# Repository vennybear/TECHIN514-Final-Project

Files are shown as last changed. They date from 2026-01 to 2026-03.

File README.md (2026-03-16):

# Door Detective: Privacy-First Ambient Entry System

> **"A smart doorbell that hears the rhythm, not the person."**

**Door Detective** is a "Calm Technology" smart home solution designed to replace invasive cameras and distracting phone notifications. By using acoustic vibration sensing and temporal pattern analysis, it identifies visitors based on their knocking rhythm and provides a physical, non-intrusive notification on a desktop gauge.

---

## Hero Shot


---

## Core Concept
Most smart doorbells compromise domestic privacy by recording video and demanding constant attention through push notifications. 
**Door Detective solves this by:**
1. **Privacy-Preserving Sensing**: Using an accelerometer instead of a camera.
2. **Ambient Notification**: Using a physical needle and an analog gauge for "at-a-glance" awareness.
3. **Edge Intelligence**: Classifying visitors locally using vibration signatures.

---

## System Architecture
The system consists of two nodes communicating via the **ESP-NOW** protocol for ultra-low latency (<100ms) without the need for a router.

*   **Sensing Node (The "Ear")**: Mounted on the door. It captures high-frequency vibration data using an LIS3DH sensor and processes it on an ESP32 DevKit.
*   **Display Node (The "Face")**: Sits on the desk. A Seeed Studio XIAO ESP32C3 receives signals and actuates an X27 stepper motor to move the needle.

---

## Hardware Specifications

| Component | Category | Details |
| :--- | :--- | :--- |
| **MCU 1** | Sensing | ESP32 DevKit V1 |
| **MCU 2** | Display | Seeed Studio XIAO ESP32C3 |
| **Sensor** | Vibration | Adafruit LIS3DH (3-Axis Accelerometer) |
| **Actuator** | Motor | X27.168 Bipolar Stepper Motor |
| **Power** | Battery | 3.7V 1000mAh LiPo (Sensing Node) |
| **Interface** | Button | 16mm Latching Push Button |
| **Enclosure** | Manufacturing | Custom 3D-printed (Fusion 360) |

---

## Software & DSP Algorithm
To fulfill the machine learning/DSP requirements, I developed a **Temporal Feature Extraction** pipeline:

1. **Signal Magnitude Vector (SMV)**: Combines X, Y, and Z axes to normalize energy readings regardless of sensor orientation.
2. **Inter-Knock Interval (IKI) Analysis**: Measures the time between peaks to classify intent:
    *   **Urgent (Delivery)**: IKI < 500ms (Rapid double-tap) ➜ Needle points Left.
    *   **Social (Friend)**: IKI 500-1200ms (Rhythmic knock) ➜ Needle points Right.
    *   **General (Guest)**: Single tap / Timeout ➜ Needle points Center.

**Accuracy**: ~85% during internal validation testing.

---

## Hardware Iteration & Lessons Learned
This project was a journey of engineering resilience.
*   **PCB Rev 1.0 Fail**: A footprint pitch mismatch caused the ESP32 headers to be too narrow.
*   **Scrappy Prototyping**: Instead of waiting for a re-milling, I pivoted to a fly-wire assembly strategy to validate the I2C bus and electrical logic.
*   **Final Revision**: The sensing node now features a custom single-sided PCB with integrated pull-up resistors and optimized power traces.

---

## Power Management
*   **Strategy**: Implemented a software-based **Timed Light Sleep** mode (50ms cycles).
*   **Performance**: Reduced average idle current from 80mA to ~15mA, allowing the 1000mAh battery to last through long periods of monitoring.
*   **Future Work**: Routing the LIS3DH interrupt pin to enable true hardware Deep Sleep (uA levels).

---

## Repository Structure
*   `/src`: Firmware for both Sensing and Display nodes.
*   `/hardware`: KiCad schematics, PCB layout, and Gerber files.
*   `/cad`: Fusion 360 3D models (.f3d and .step).
*   `/docs`: Datasheets, Power calculation spreadsheet, and FMEA report.

---

## Author
**Yuna Xiong**
Technology Innovation (MSTI) Graduate Student at the University of Washington.

---

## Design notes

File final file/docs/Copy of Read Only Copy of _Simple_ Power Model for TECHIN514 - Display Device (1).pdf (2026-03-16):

System Parameters (defined by hardware) | Profiles (usage of each component mode - defined by software and usage)
form the datasheets
"off" | "sensing" | "interactive" Processor Active | 530 mW | 0% | 0% | 100%
Idle | 50 mW | 0% | 100% | 0%
Sleep | 0 mW | 100% | 0% | 0%
LED On | 15 mW | 0% | 0% | 100%
Sensor On | 1 mW | 100% | 100% | 100%
Idle | 0 mW | 0% | 0% | 0%
Off | 0 mW | 0% | 0% | 0%
Display (https://github.com/vennybear/TECHIN514-Final-Project/blob/main/datasheets/stepd-01-data-sheet-1143075.pdf) On | 1200 mW | 0% | 0% | 100%
Off (leakage) | 0 mW | 0% | 0% | 0%
Radio Data Rate | 0 bps | 0% | 0% | 0% | Total power in profile (mw) | Maximum Time Standby Power | 0 mW | 0% | 0% | 0% | "off" | 1.1 mW | 6054.5 hours TX Power | 0 mW | 0% | 0% | 0% | "sensing" | 51 mW | 130.6 hours RX Power | 0 mW | 0% | 0% | 0% | "interactive" | 1746 mW | 3.8 hours
23.95 | 0 | 0.05 hours/day typical usage | Effective Battery Capacity Battery | 6660 mW*h Capacity | 2000 mAh Nominal Voltage | 4 V | Days of Use | 58.60 days Regulator Efficiency | 90% | Hours of Use | 1406.49 hours

REFLECTIONS : WHAT DID YOU LEARN FROM ANALYZING YOUR POWER. TALK ABOUT SOME POTENTIAL TRADEOFFS. Reflections on Power Analysis:

1. Determining the "Days of Use" Metric:
I calculated the usage based on a scenario of 20 visitors per day. For the Sensing Device, I assumed each event takes 10 seconds to wake up, process the vibration, and transmit data via WiFi. This results in a very low duty cycle where the device spends 99.9% of its time in Deep Sleep.
2. Optimum Battery Size: For the Sensing Device, a 1000mAh LiPo is the optimum size because it is thin enough to fit inside a small door-mounted enclosure while providing over 50 days of battery life. For the Display Device, a 2000mAh battery or direct USB power is better since the stepper motor consumes significant power 1200mW) during interaction.
3. Hardware/Software Tradeoffs: To improve the user experience and battery life, I could implement the ESPNOW protocol instead of standard WiFi to reduce the handshake time from seconds to milliseconds. Another tradeoff would be using a low-power E-ink display instead of a motor, but that would lose the "calm tech" physical interaction which is a key design goal of this project.

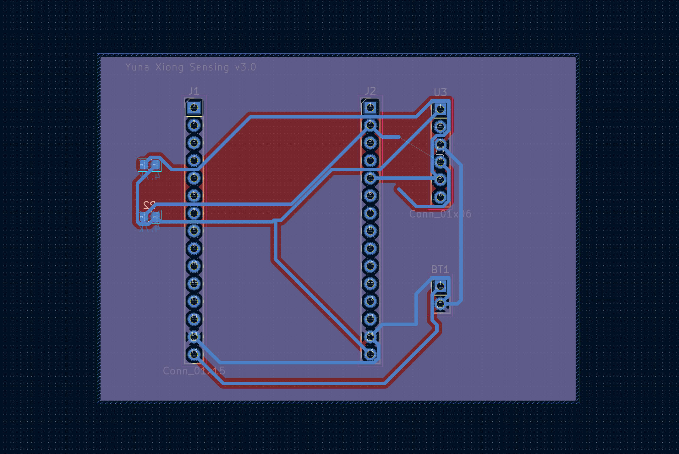
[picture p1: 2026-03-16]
final file/hardware/pcb.jpg

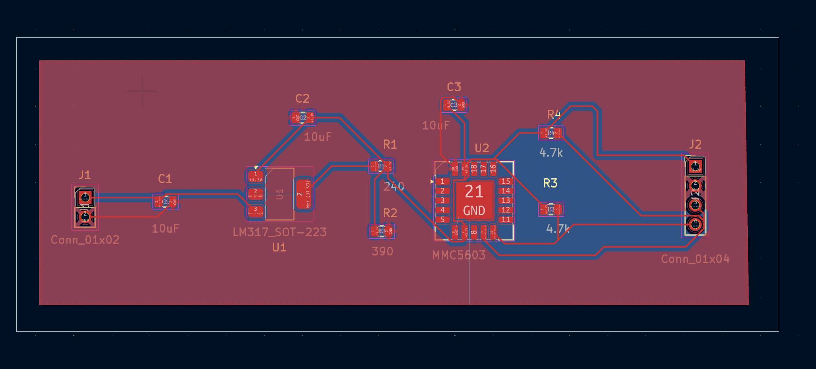
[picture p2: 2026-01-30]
PCB.png

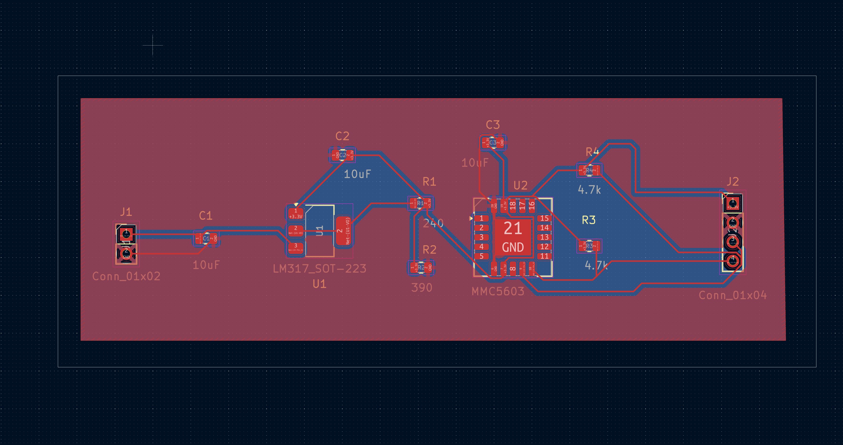
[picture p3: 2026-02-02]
screenshot pcb v2.png

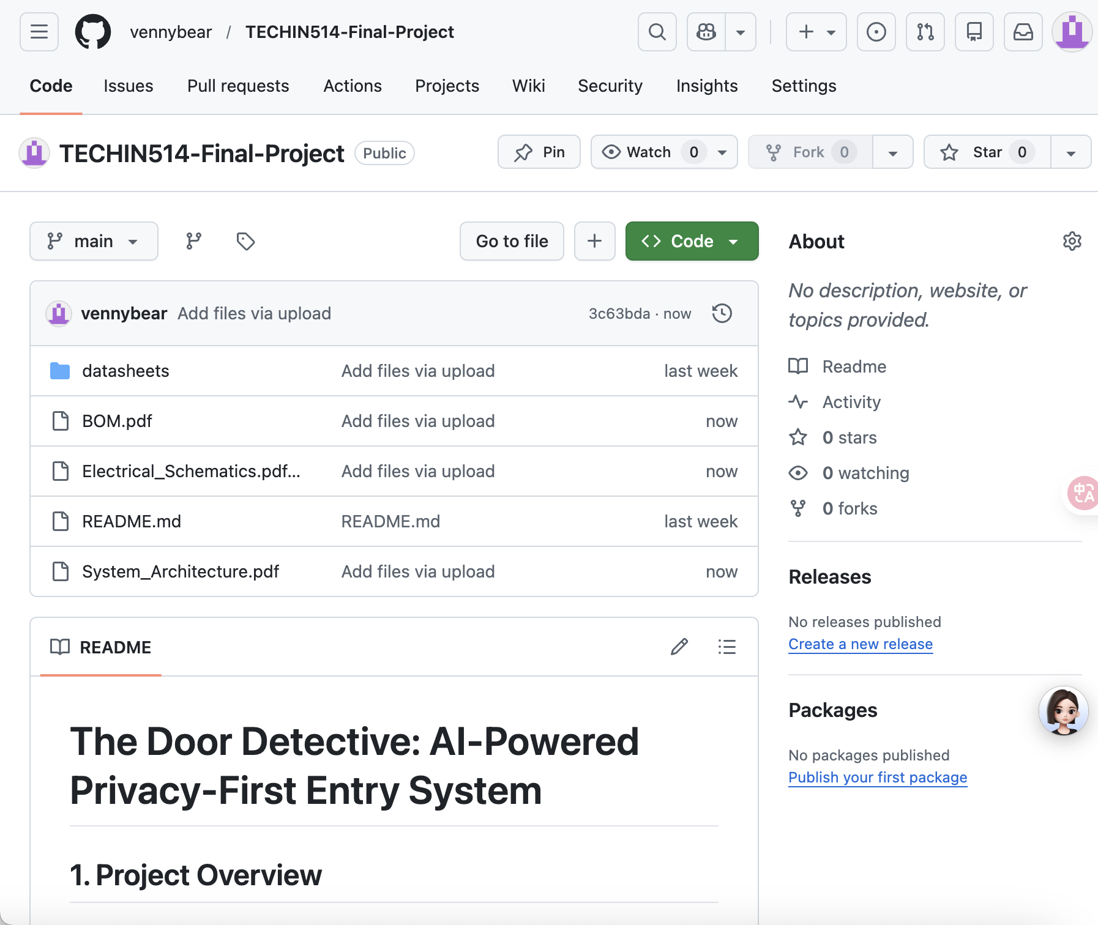
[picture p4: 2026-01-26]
screenshot 1.26.png

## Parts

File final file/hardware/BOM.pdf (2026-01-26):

Item | Quantity | Part Number | Description | Manufacturer Package
1 | 2 | ESP32WROOM32E ESP32 Development Board WiFi/BLE Espressif | | | DevKit V1
2 | 1 | LIS3DH | 3Axis Accelerometer Breakout Board I2C STMicroelectronics Breakout
3 | 1 | 28BYJ48 | 5V Stepper Motor Generic | | Motor
4 | 1 | ULN2003 | Stepper Motor Driver Board Generic | | Module
5 | 1 | LP503035 | LiPo Battery 3.7V 1000mAh Generic | | Pouch
6 | 1 | TP4056 | USBC LiPo Battery Charging Module Generic | | Module
7 | 1 | USBC Cable | USB Type-A to Type-C Cable Generic | | Cable

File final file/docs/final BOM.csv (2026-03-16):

Item | Quantity | Part Number / Model | Description | Manufacturer | Package
1 | 1 | ESP32-WROOM-32E | Main Controller (Sensing Node) | Espressif | DevKit V1
2 | 1 | XIAO ESP32C3 | Main Controller (Display Node) | Seeed Studio | Module
3 | 1 | Adafruit LIS3DH | 3-Axis Accelerometer | Adafruit | Breakout
4 | 1 | X27.168 | Bipolar Stepper Motor | Generic / Lab | Motor
5 | 2 | 4.7k Ω | I2C Pull-up Resistors | Generic | SMD 0805
6 | 1 | PL 503450 | LiPo Battery 3.7V 1000mAh | Generic | Pouch
7 | 1 | 16mm Latching Button | Manual Reset Switch | Generic | Panel Mount
8 | 1 | 5mm LED + 220Ω Resistor | Status Indicator | Generic | Through-hole

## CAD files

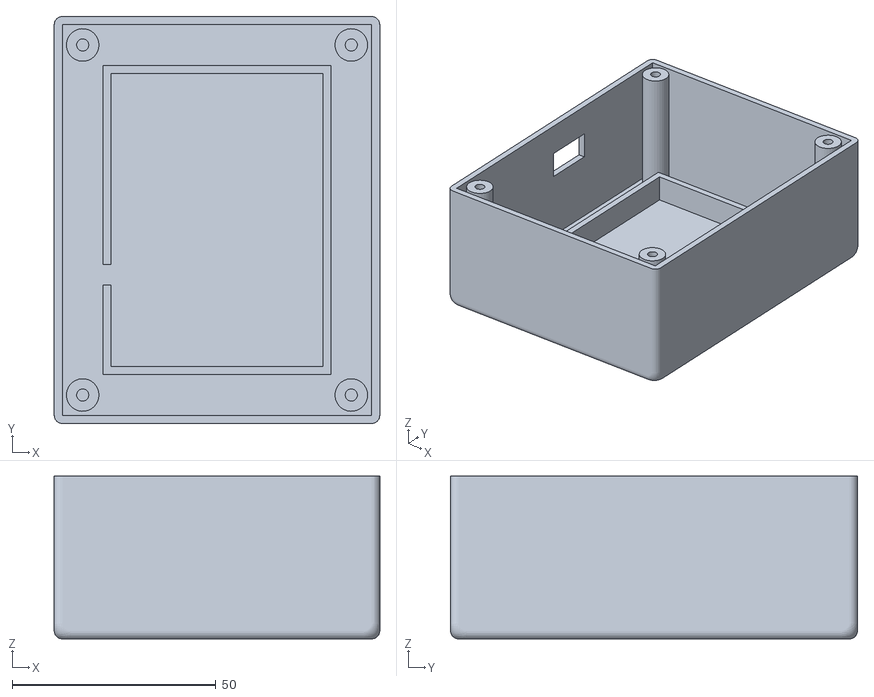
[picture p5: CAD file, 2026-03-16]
final file/cad/door detective shell BASE V3.stl
80.0 x 100.0 x 40.0

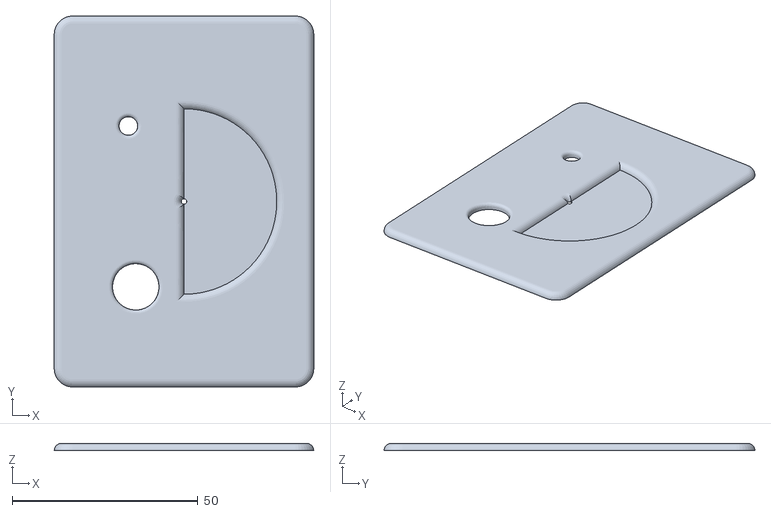
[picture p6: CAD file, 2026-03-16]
final file/cad/Display Device v3 top.stl
70.0 x 100.0 x 2.00

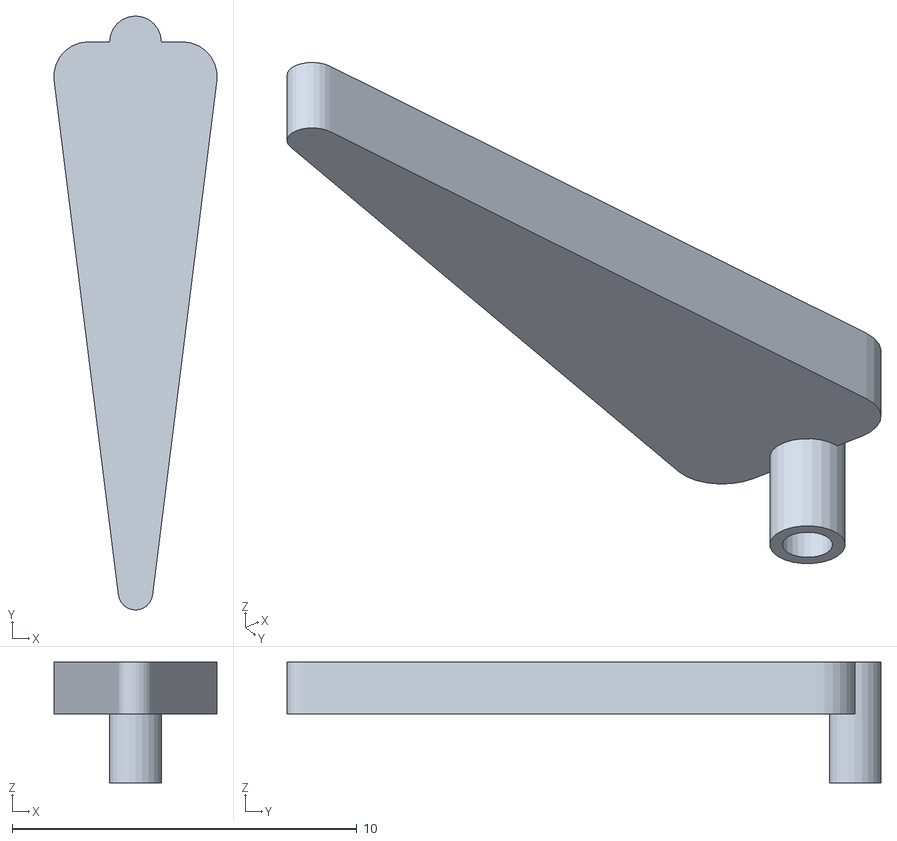
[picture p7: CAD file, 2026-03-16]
final file/cad/needle.stl
4.72 x 17.2 x 3.50

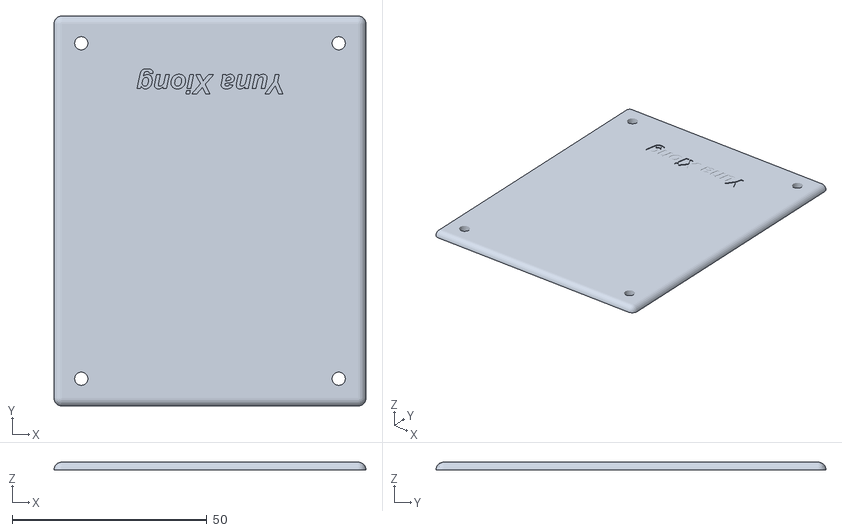
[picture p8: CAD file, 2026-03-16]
final file/cad/door detective shell TOP V3.stl
80.0 x 100.0 x 2.00

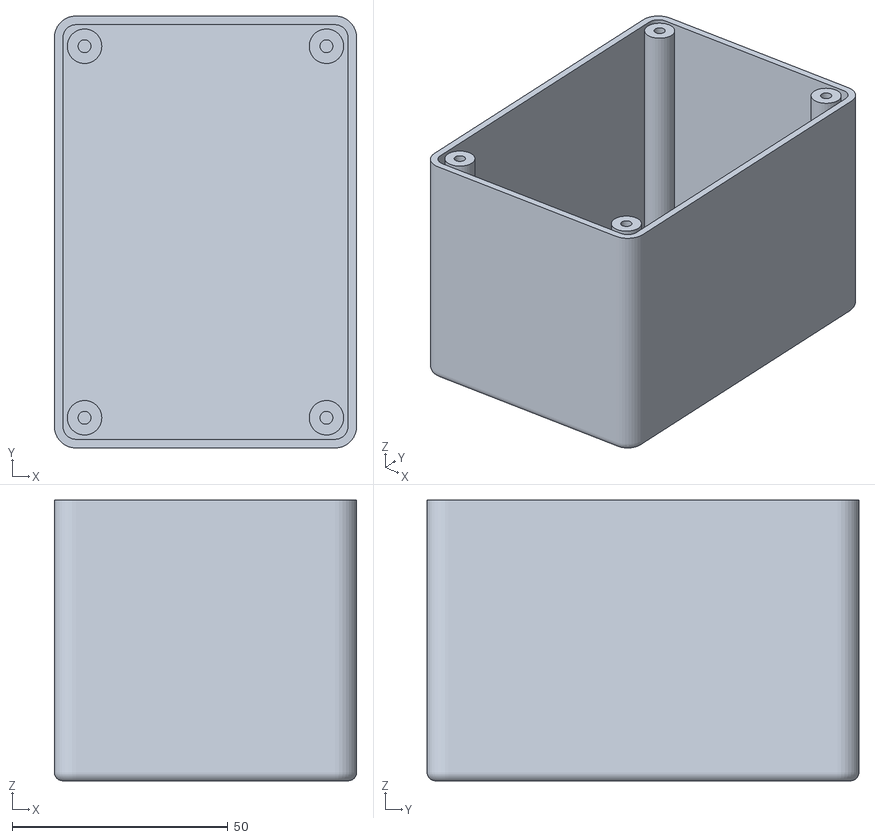
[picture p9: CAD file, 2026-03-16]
final file/cad/Display Device v3 base.stl
70.0 x 100.0 x 65.0

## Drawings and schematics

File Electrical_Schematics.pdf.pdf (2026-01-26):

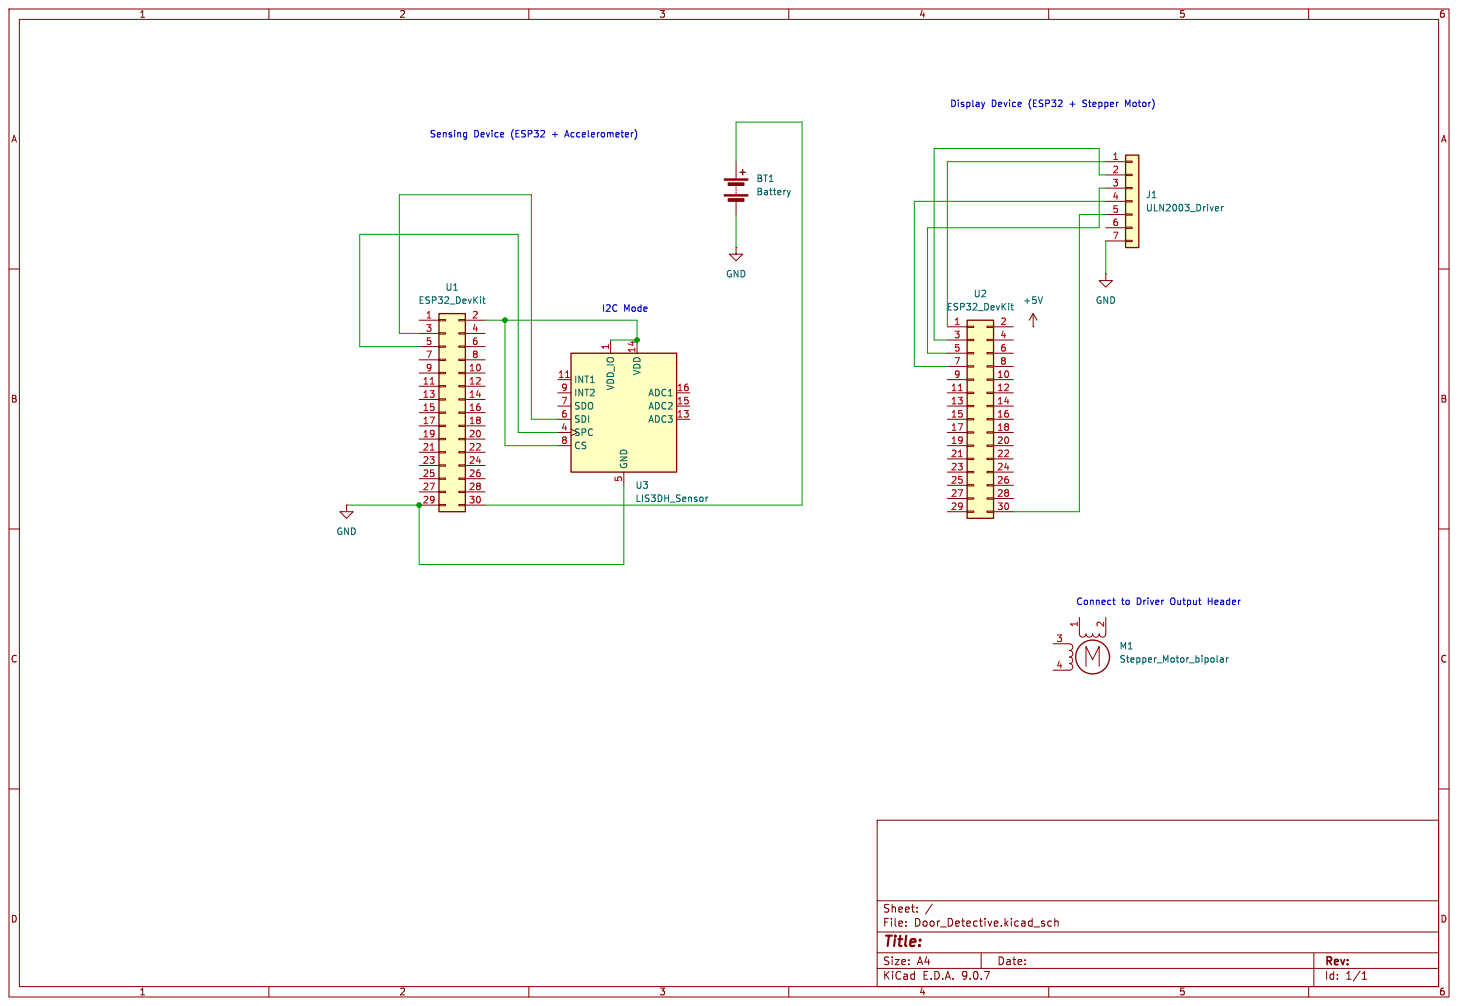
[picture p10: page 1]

Display Device (ESP32 + Stepper Motor)

Id: 1/1 Title: File: Door_Detective.kicad_sch Sheet: /

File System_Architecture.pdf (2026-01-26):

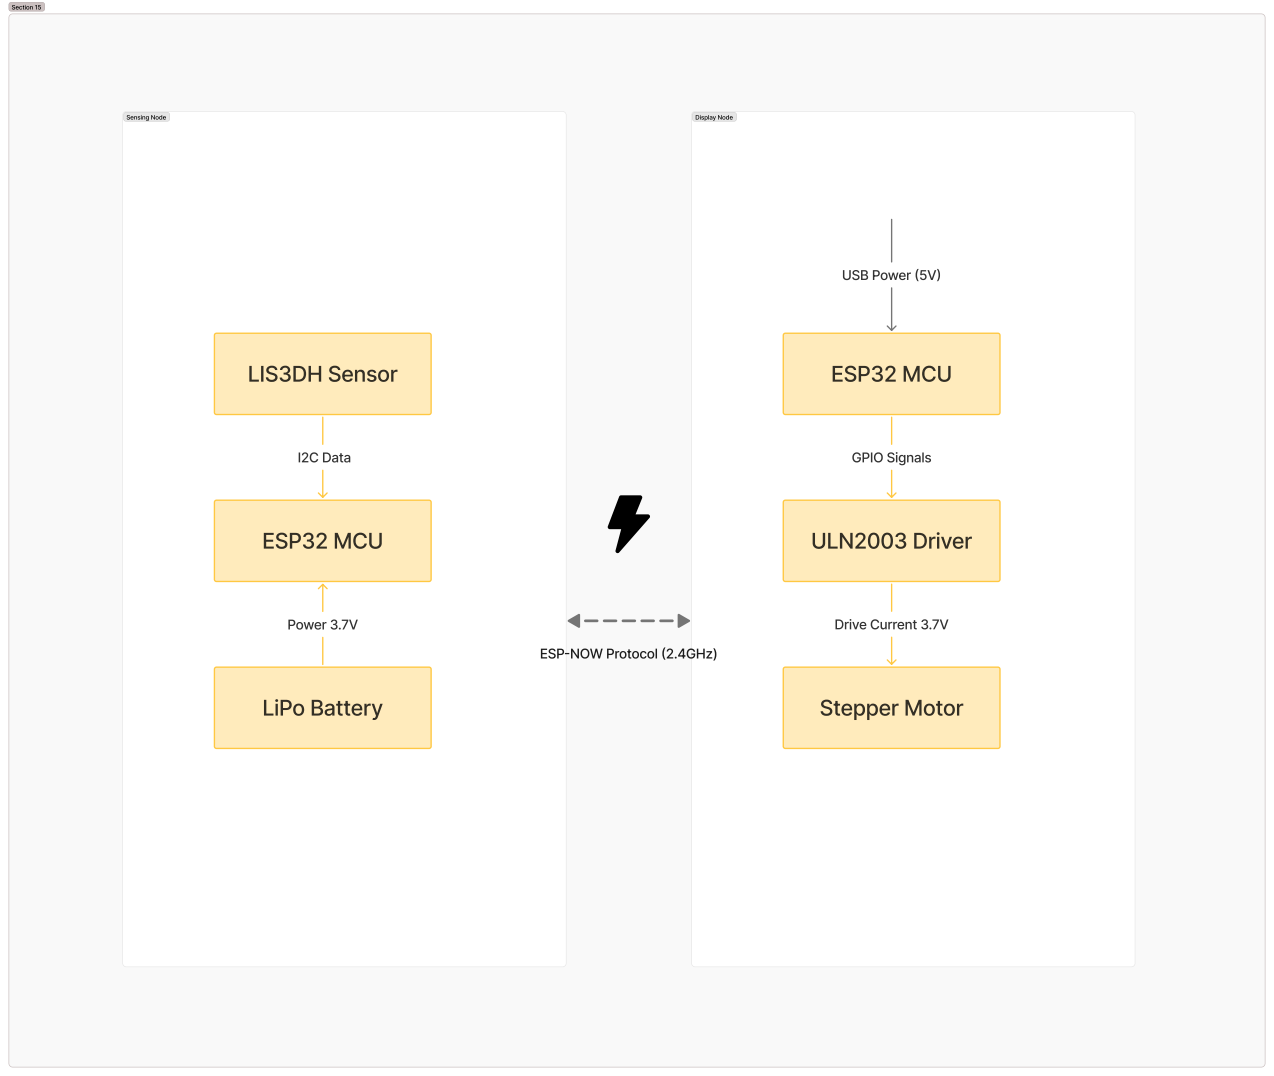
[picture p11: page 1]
LIS3DH Sensor; ESP32 MCU; LiPo Battery; I2C Data; Power 3.7V; USB Power (5V); ULN2003 Driver; Stepper Motor; GPIO Signals; Drive Current 3.7V; Sensing Node; Display Node; Section 15

ESP-NOW Protocol (2.4GHz)

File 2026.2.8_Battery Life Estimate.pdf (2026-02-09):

System Parameters (defined by hardware) | Profiles (usage of each component mode - defined by software and usage)
form the datasheets
"off" | "sensing" | "interactive" Processor Active | 530 mW | 0% | 0% | 100%
Idle | 50 mW | 0% | 100% | 0%
Sleep | 0 mW | 100% | 0% | 0%
LED On | 0 mW | 0% | 0% | 0%
Sensor On | 0 mW | 0% | 0% | 0%
Idle | 0 mW | 0% | 0% | 0%
Off | 0 mW | 0% | 0% | 0%
Display (https://github.com/vennybear/TECHIN514-Final-Project/blob/main/datasheets/stepd-01-data-sheet-1143075.pdf) On | 1200 mW | 0% | 0% | 100%
Off (leakage) | 0 mW | 0% | 0% | 0%
Radio Data Rate | 0 bps | 0% | 0% | 0% | Total power in profile (mw) | Maximum Time Standby Power | 0 mW | 0% | 0% | 0% | "off" | 0.1 mW | 66600.0 hours TX Power | 0 mW | 0% | 0% | 0% | "sensing" | 50 mW | 133.2 hours RX Power | 0 mW | 0% | 0% | 0% | "interactive" | 1730 mW | 3.8 hours
23.95 | 0 | 0.05 hours/day typical usage | Effective Battery Capacity Battery | 6660 mW*h Capacity | 2000 mAh Nominal Voltage | 4 V | Days of Use | 74.92 days Regulator Efficiency | 90% | Hours of Use | 1798.08 hours

REFLECTIONS : WHAT DID YOU LEARN FROM ANALYZING YOUR POWER. TALK ABOUT SOME POTENTIAL TRADEOFFS. Reflections on Power Analysis:

## 1. Determining the "Days of Use" Metric:

I calculated the usage based on a scenario of 20 visitors per day. For the Sensing Device, I assumed each event takes 10 seconds to wake up, process the vibration, and transmit data via WiFi. This results in a very low duty cycle where the device spends 99.9% of its time in Deep Sleep.

2. Optimum Battery Size: For the Sensing Device, a 1000mAh LiPo is the optimum size because it is thin enough to fit inside a small door-mounted enclosure while providing over 50 days of battery life. For the Display Device, a 2000mAh battery or direct USB power is better since the stepper motor consumes significant power 1200mW) during interaction.
3. Hardware/Software Tradeoffs: To improve the user experience and battery life, I could implement the ESPNOW protocol instead of standard WiFi to reduce the handshake time from seconds to milliseconds. Another tradeoff would be using a low-power E-ink display instead of a motor, but that would lose the "calm tech" physical interaction which is a key design goal of this project.

System Parameters (defined by hardware) | Profiles (usage of each component mode - defined by software and usage)
form the datasheets
"off" | "sensing" | "interactive" Processor Active | 530 mW | 0% | 0% | 100%
Idle | 50 mW | 0% | 100% | 0%
Sleep | 0 mW | 100% | 0% | 0%
LED On | 0 mW | 0% | 0% | 0%
Sensor (https://github.com/vennybear/TECHIN514-Final-Project/blob/main/datasheets/lis3dh.pdf) On | 0 mW | 100% | 100% | 100%
Idle | 0 mW | 0% | 0% | 0%
Off | 0 mW | 0% | 0% | 0%
Display On | 0 mW | 0% | 0% | 0%
Off (leakage) | 0 mW | 0% | 0% | 0%
Radio Data Rate | 0 bps | 0% | 0% | 0% | Total power in profile (mw) | Maximum Time Standby Power | 0 mW | 0% | 0% | 0% | "off" | 0.2 mW | 16650.0 hours TX Power | 0 mW | 0% | 0% | 0% | "sensing" | 50.1 mW | 66.5 hours RX Power | 0 mW | 0% | 0% | 0% | "interactive" | 530.1 mW | 6.3 hours
23.9 | 0 | 0.1 hours/day typical usage | Effective Battery Capacity Battery | 3330 mW*h Capacity | 1000 mAh Nominal Voltage | 4 V | Days of Use | 57.62 days Regulator Efficiency | 90% | Hours of Use | 1382.94 hours

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

## 1. Determining the "Days of Use" Metric:

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

2. Optimum Battery Size: For the Sensing Device, a 1000mAh LiPo is the optimum size because it is thin enough to fit inside a small door-mounted enclosure while providing over 50 days of battery life. For the Display Device, a 2000mAh battery or direct USB power is better since the stepper motor consumes significant power 1200mW) during interaction.
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

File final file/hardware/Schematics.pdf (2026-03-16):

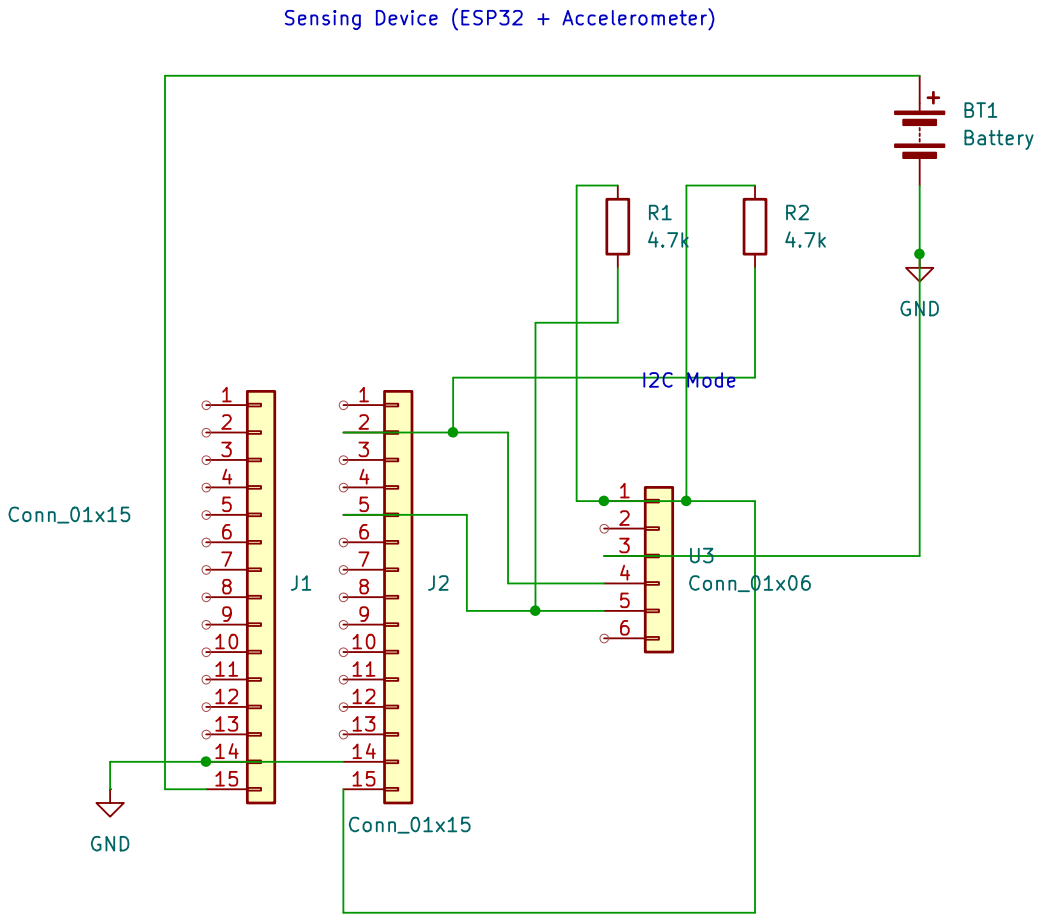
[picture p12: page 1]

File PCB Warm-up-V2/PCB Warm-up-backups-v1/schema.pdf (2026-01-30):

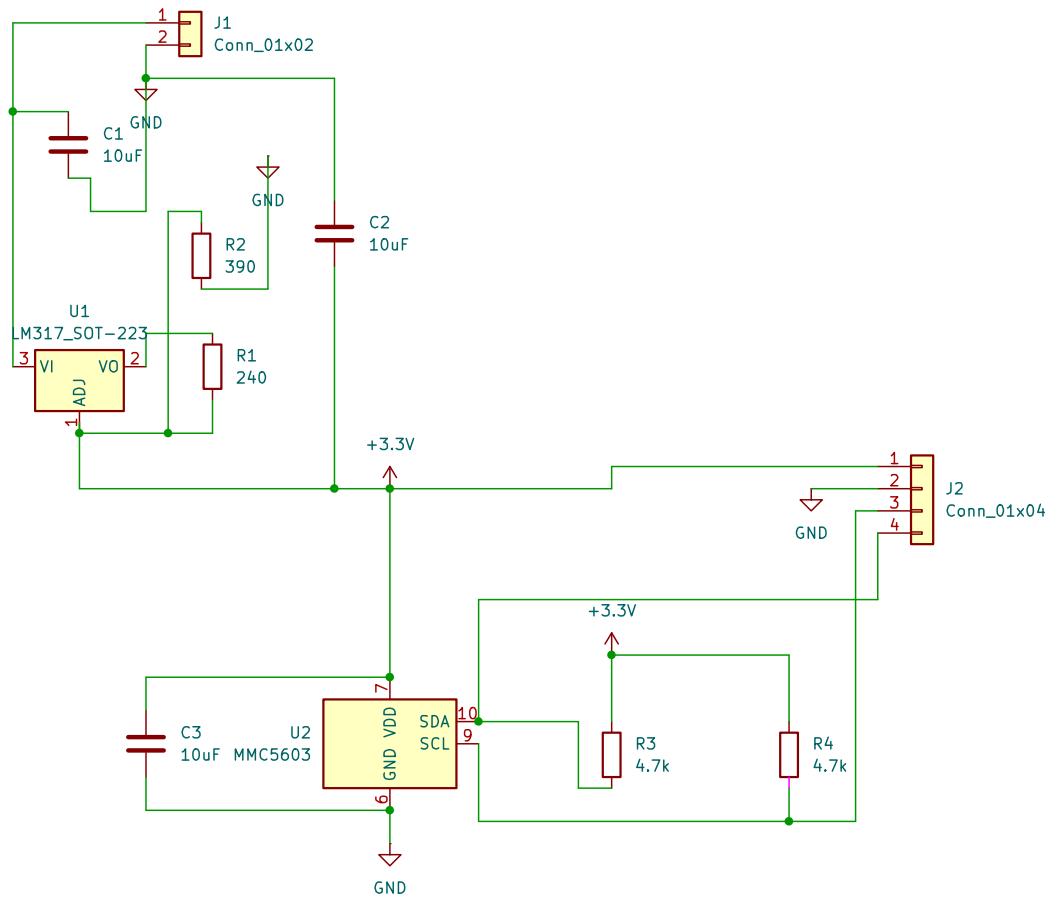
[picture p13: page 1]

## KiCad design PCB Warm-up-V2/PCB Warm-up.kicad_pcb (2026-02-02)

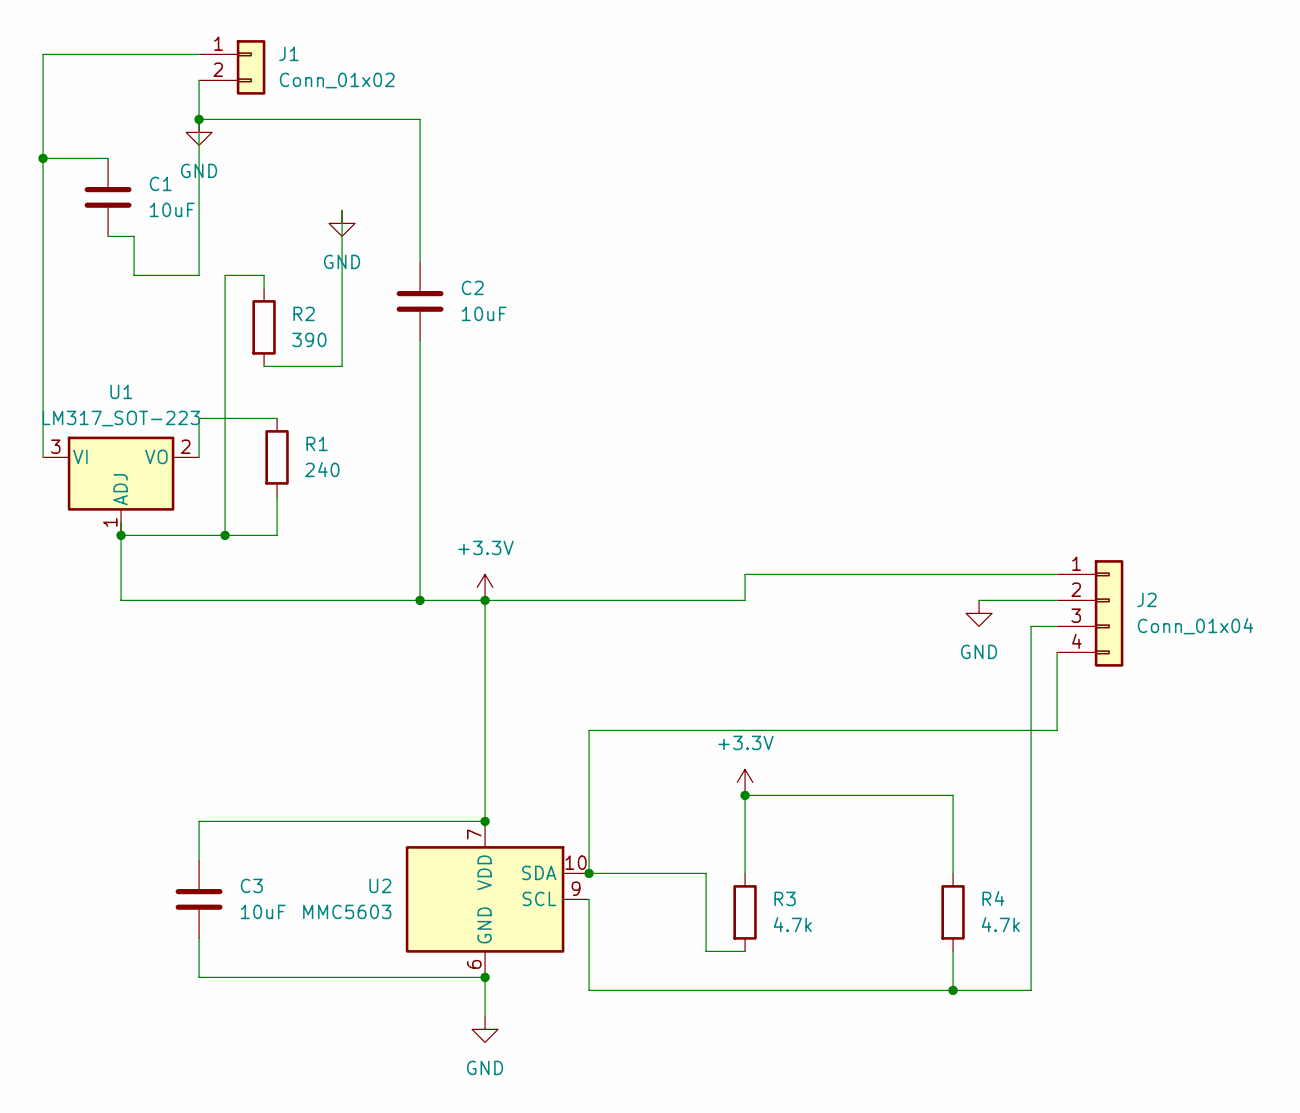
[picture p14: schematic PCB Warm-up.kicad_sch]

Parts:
C1, C2, C3: 10uF; C_0805_2012Metric
J1: Conn_01x02; PinHeader_1x02_P2.54mm_Vertical
J2: Conn_01x04; PinHeader_1x04_P2.54mm_Vertical
R1: 240; R_0805_2012Metric
R2: 390; R_0805_2012Metric
R3, R4: 4.7k; R_0805_2012Metric
U1: LM317_SOT-223; SOT-223-3_TabPin2
U2: MMC5603; Sensirion_SCD4x-1EP_10.1x10.1mm_P1.25mm_EP4.8x4.8mm

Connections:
+3.3V: C2.2, C3.1, J2.1, R1.2, R2.1, R3.1, R4.1, U1.1 (ADJ), U2.7 (VDD), U2.19 (VDD)
GND: C1.2, C2.1, C3.2, J1.2, J2.2, R2.2, U2.6 (GND), U2.20 (GND), U2.21 (GND)
unnamed: C1.1, J1.1, U1.3 (VI)
unnamed: J2.3, R4.2, U2.9 (SCL)
unnamed: J2.4, R3.2, U2.10 (SDA)
unnamed: R1.1, U1.2 (VO)

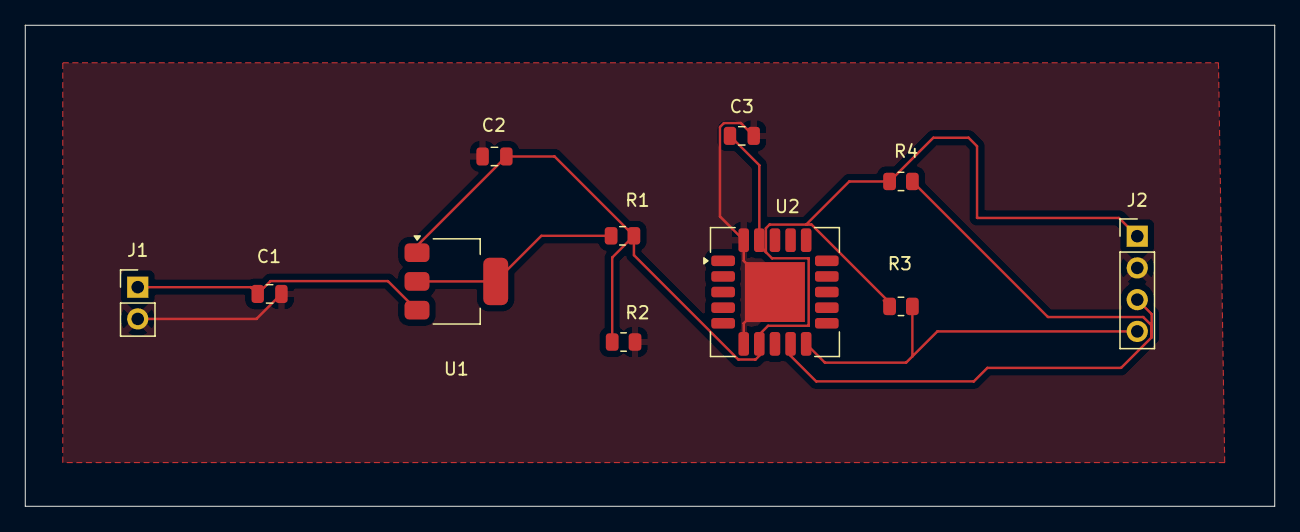
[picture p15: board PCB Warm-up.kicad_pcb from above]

Board: 2 copper layers, 100.0 x 38.5 mm, 11 parts (0 on the bottom side), 6 nets.

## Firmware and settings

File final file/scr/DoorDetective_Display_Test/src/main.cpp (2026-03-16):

#include <Arduino.h>
#include <esp_now.h>
#include <WiFi.h>
#include <Stepper.h>

// 1. 硬件引脚
Stepper myStepper(600, D0, D2, D1, D3); 
const int buttonPin = D4; // 自锁大黑按钮
const int ledPin = D5;

// 2. 全局状态
String lastMsg = "";
bool wirelessTriggered = false;
int lastButtonState; 
const int motorSpeed = 20;

// 接收回调
void OnDataRecv(const uint8_t * mac, const uint8_t *incomingData, int len) {
    char buffer[len + 1];
    memcpy(buffer, incomingData, len);
    buffer[len] = '\0';
    lastMsg = String(buffer);
    wirelessTriggered = true;
}

// 自锁开关翻转检测
bool checkButtonToggle() {
    int currentState = digitalRead(buttonPin);
    if (currentState != lastButtonState) {
        delay(50); // 防抖
        lastButtonState = currentState;
        return true;
    }
    return false;
}

void setup() {
    Serial.begin(115200);
    WiFi.mode(WIFI_STA);
    if (esp_now_init() == ESP_OK) {
        esp_now_register_recv_cb(esp_now_recv_cb_t(OnDataRecv));
    }

    myStepper.setSpeed(motorSpeed);
    pinMode(ledPin, OUTPUT);
    pinMode(buttonPin, INPUT_PULLUP);
    lastButtonState = digitalRead(buttonPin);

    // 开机闪烁
    for(int i=0; i<3; i++) { digitalWrite(ledPin, HIGH); delay(100); digitalWrite(ledPin, LOW); delay(100); }
    Serial.println("Display Unit READY for Classification!");
}

// 核心执行逻辑：根据不同步数转动，并支持 8s 内随时按按钮取消
void runNotification(int steps, int mode) {
    // mode 0 = 敲门（灯长亮），mode 1 = 自检（灯闪烁）
    Serial.print("Moving steps: "); Serial.println(steps);
    
    digitalWrite(ledPin, HIGH);
    myStepper.step(steps);

    // 8 秒停留，期间只要拨动按钮，立刻 break
    for (int i = 0; i < 80; i++) {
        if (mode == 0) digitalWrite(ledPin, HIGH);
        else digitalWrite(ledPin, (i % 2 == 0));
        
        delay(100);

        if (checkButtonToggle()) {
            Serial.println("Manual Dismissed!");
            break; 
        }
    }

    digitalWrite(ledPin, LOW);
    myStepper.step(-steps); // 复位
}

void loop() {
    if (wirelessTriggered) {
        int steps = 180; // 默认：正上方 (Guest)
        
        if (lastMsg == "DELIVERY") {
            steps = 90;  // 45度位置
        } else if (lastMsg == "FRIEND") {
            steps = 270; // 135度位置 (你说的 270 度应该就是这里)
        }
        
        Serial.print("Moving to steps: "); Serial.println(steps);
        runNotification(steps, 0); 
        wirelessTriggered = false;
    }

    // 逻辑 B: 手动按钮触发 (自检)
    if (checkButtonToggle()) {
        Serial.println("Manual Button Event");
        runNotification(150, 1); // 运行闪烁自检
    }
}

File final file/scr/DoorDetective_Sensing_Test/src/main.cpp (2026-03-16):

#include <Arduino.h>
#include <esp_now.h>
#include <WiFi.h>
#include <Adafruit_LIS3DH.h>
#include <Adafruit_Sensor.h>
#include "esp_sleep.h"

/* 
 * Door Detective - Final Sensing Node (PCB)
 * Logic: Temporal Pattern Recognition (DSP)
 * Author: Yuna Xiong
 */

// 1. 硬件与通信设置
Adafruit_LIS3DH lis = Adafruit_LIS3DH();
// 这里是你的 Display 端 XIAO C3 的 MAC 地址
uint8_t broadcastAddress[] = {0x58, 0x8C, 0x81, 0x9D, 0x62, 0x34};

// 2. 算法变量
unsigned long firstKnockTime = 0;
int knockStep = 0;           // 状态机：0-等待第一下，1-等待第二下
const float threshold = 13.5; // 震动阈值（根据实测微调：8.0灵敏，15.0迟钝）
const int minInterval = 200;  // 两次敲击之间最小间隔（ms），用于防抖

// 发送状态反馈
void OnDataSent(const uint8_t *mac_addr, esp_now_send_status_t status) {
  Serial.print("\r\nPacket Send Status: ");
  Serial.println(status == ESP_NOW_SEND_SUCCESS ? "Success" : "Fail");
}

void setup() {
  Serial.begin(115200);

  // 初始化 WiFi 和 ESP-NOW
  WiFi.mode(WIFI_STA);
  WiFi.disconnect(); 
  if (esp_now_init() != ESP_OK) {
    Serial.println("ESP-NOW Init Failed");
    return;
  }
  esp_now_register_send_cb(OnDataSent);

  // 绑定接收端
  esp_now_peer_info_t peerInfo = {};
  memcpy(peerInfo.peer_addr, broadcastAddress, 6);
  peerInfo.channel = 0;  
  peerInfo.encrypt = false;
  if (esp_now_add_peer(&peerInfo) != ESP_OK){
    Serial.println("Failed to add peer");
    return;
  }

  // 初始化传感器
  if (!lis.begin(0x18)) {
    Serial.println("LIS3DH Not Found!");
    while (1);
  }
  lis.setRange(LIS3DH_RANGE_2_G); // 最灵敏模式
  Serial.println(">>> Door Detective: Sensing Node Ready <<<");
}

void loop() {
  sensors_event_t event;
  lis.getEvent(&event);

  // --- [DSP 步骤 1: Signal Magnitude Vector] ---
  // 计算合成加速度，过滤掉安装方向的影响
  float smv = sqrt(sq(event.acceleration.x) + sq(event.acceleration.y) + sq(event.acceleration.z));

  // --- [逻辑 2: 节奏特征提取] ---
  if (smv > threshold) {
    if (knockStep == 0) {
      // 捕获到第一下
      firstKnockTime = millis();
      knockStep = 1;
      Serial.println("First knock...");
      delay(minInterval); // 机械防抖
    } 
    else if (knockStep == 1 && (millis() - firstKnockTime > minInterval)) {
      // 捕获到第二下，计算间隔
      unsigned long interval = millis() - firstKnockTime;
      Serial.print("Interval measured: "); Serial.print(interval); Serial.println("ms");

      String result = "GUEST"; // 默认普通访客
      if (interval < 500) {
        result = "DELIVERY"; // 快速两连击：砰砰！
      } else if (interval < 1200) {
        result = "FRIEND";   // 慢速两连击：砰...砰
      }

      Serial.print("Classification: "); Serial.println(result);
      esp_now_send(broadcastAddress, (uint8_t *) result.c_str(), result.length());
      
      knockStep = 0; // 重置状态机
      delay(2000);   // 冷却，防止余震触发
    }
  }

  // 超时保护：如果敲了第一下后 2 秒没动静，归零
  if (knockStep == 1 && (millis() - firstKnockTime > 2000)) {
    knockStep = 0;
    Serial.println("Timeout, resetting pattern...");
  }

 // 先定个 50 毫秒的闹钟
  esp_sleep_enable_timer_wakeup(50 * 1000); 
  // 然后闭眼睡觉
  esp_light_sleep_start();
}
